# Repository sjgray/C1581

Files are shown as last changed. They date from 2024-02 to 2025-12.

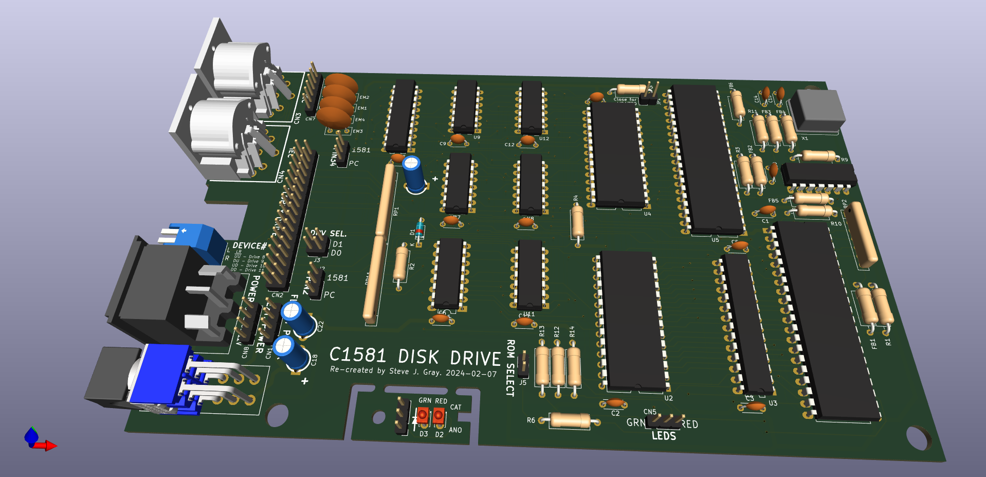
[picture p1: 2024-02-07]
Enhanced/PROTO1/_Pics/2024-02-07-pcb-render.png

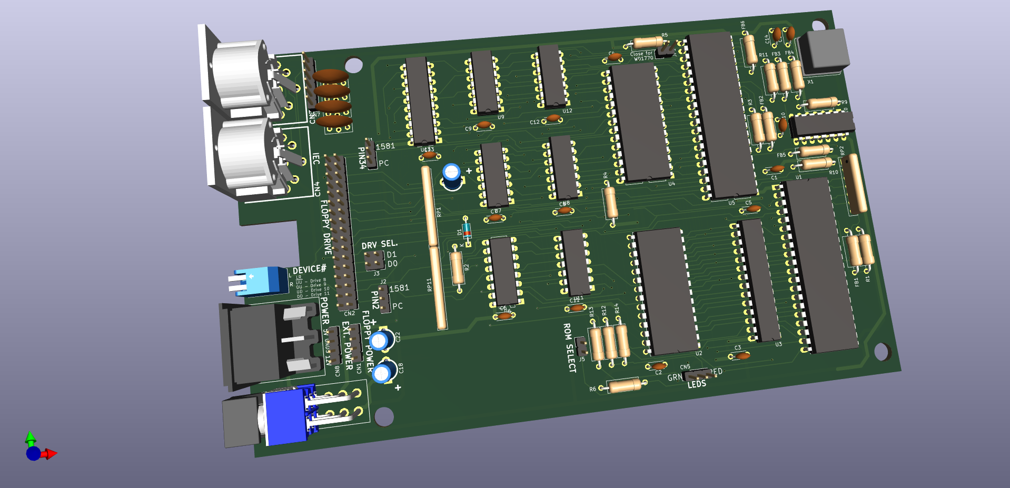
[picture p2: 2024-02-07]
Enhanced/PROTO1/_Pics/2024-02-06-pcb-render.png

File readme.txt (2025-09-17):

1581 ENHANCED PROJECT - Steve J. Gray
=====================

These are reproductions of the C1581 Disk Drive PCB.
The goal of this is to create enhanced PCBs which
can be modified, ie: reduced area for mounting 
inside a computer, increased ROM capacity, power
options, or laptop drive support, etc.

Enhancements:
- Jumpers for 1581/Amiga or PC drive.
- Jumpers for drive select 0 or 1.
- SkinnyDIP RAM chip.
- Double-size ROM with select (Standard or JiffyDOW).
- Optional header for 12V+5V internal power.
- Optional Barrel Jack for 12V power.
- Long pads for easier soldering.

ENHANCED
--------

This is a version with the same layout as the original,
with all original features and ports, plus all
enhancements. It can be installed in an original or
reproduction case. It includes the breakaway LED board.
It can also be powered with a 12V supply by replacing
the original 4-PIN DIN with the barrel jack.

INTERNAL
--------

This is a compact version with a slightly arranged
layout to pack the chips closer together. It removes
the DIN connectors, and LED breakaway.

*****************************************************
** The schematics and PCBs have NOT been verified! **
** Use at own risk!                                **
*****************************************************

Steve

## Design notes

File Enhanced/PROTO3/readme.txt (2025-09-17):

1581 ENHANCED VERSION - PROTO 2
===============================

This is a reproduction of the C1541 Disk Drive PCB.
The goal of this is to create an enhanced PCB which
can be modified, ie: reduced area for mounting 
inside a computer.

Enhancements:
- Jumpers for 1581/Amiga or PC drive.
- Jumpers for drive select 0 or 1.
- SkinnyDIP RAM chip.
- Double-size ROM with select (Standard or JiffyDOW).
- Optional header for 12V+5V internal power.
- Optional Barrel Jack for 12V power.
- Long pads for easier soldering.

*********************************************
*** DESIGN NOT VERIFIED! USE AT OWN RISK! ***
*********************************************

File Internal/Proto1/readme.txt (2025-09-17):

1581i - Internal Version - PROTO 1
========================

This is a reproduction of the C1581 Disk Drive PCB.
The goal of this is to create an enhanced PCB which
can be modified, ie: reduced area for mounting 
inside a computer.

Enhancements:
- Jumpers for 1581/Amiga or PC drive.
- Jumpers for drive select 0 or 1.
- SkinnyDIP RAM chip.
- Double-size ROM with select (Standard or JiffyDOW).
- Optional header for 12V+5V internal power.
- Optional Barrel Jack for 12V power.
- FPC connector for Laptop PC Drive.
- Long pads for easier soldering.

**** THIS VERSION HAS ERRORS! **** Use PROTO 2!
Steve

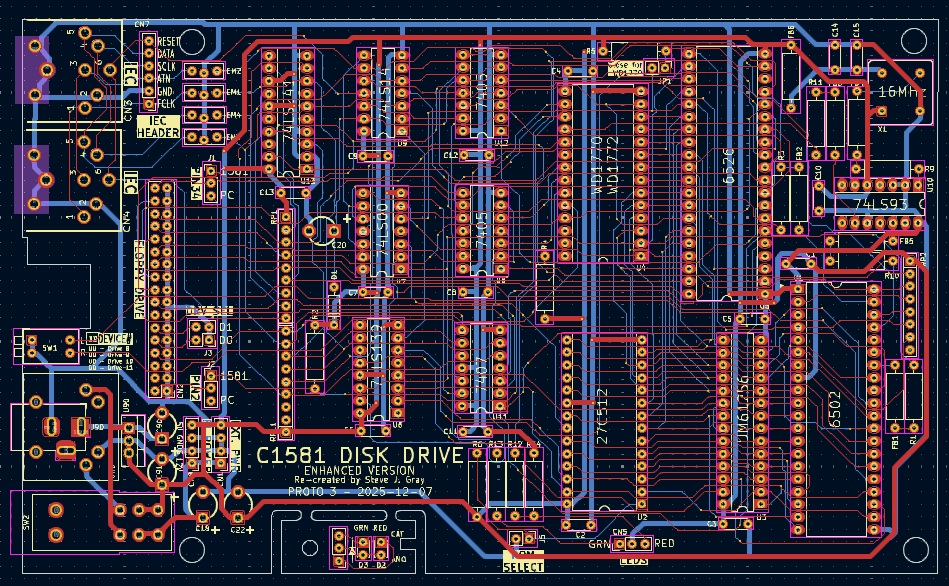
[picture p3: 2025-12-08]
Enhanced/PROTO3/_Pics/routed.jpg

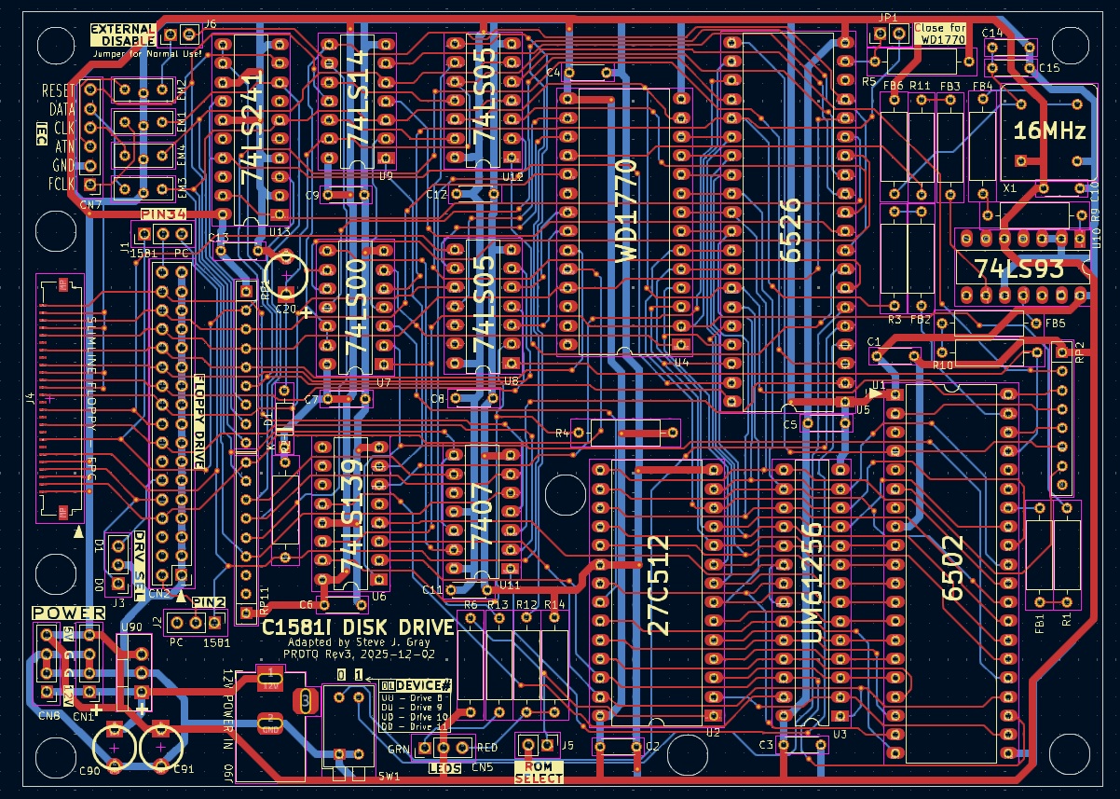
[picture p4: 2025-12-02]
Internal/Proto3/_Pics/2025-12-02-Routed.jpg

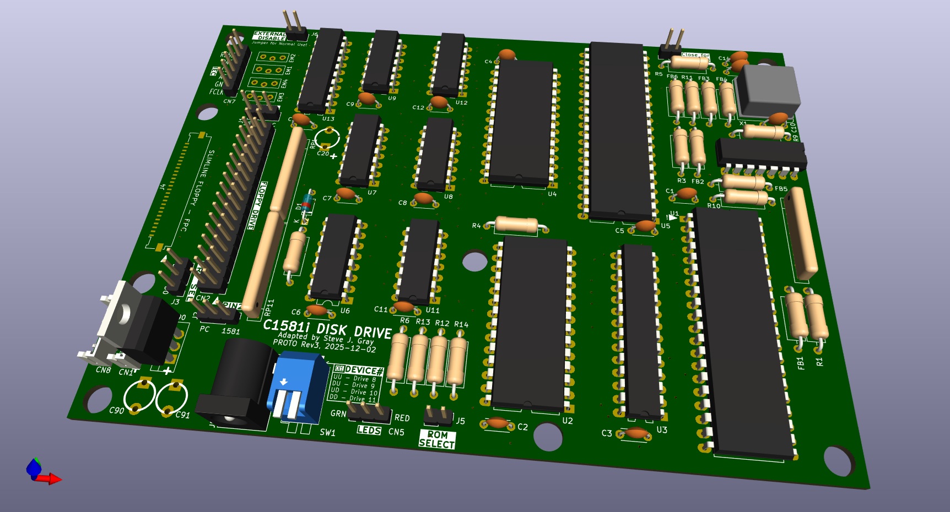
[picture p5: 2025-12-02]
Internal/Proto3/_Pics/2025-12-02-Render-angle.jpg

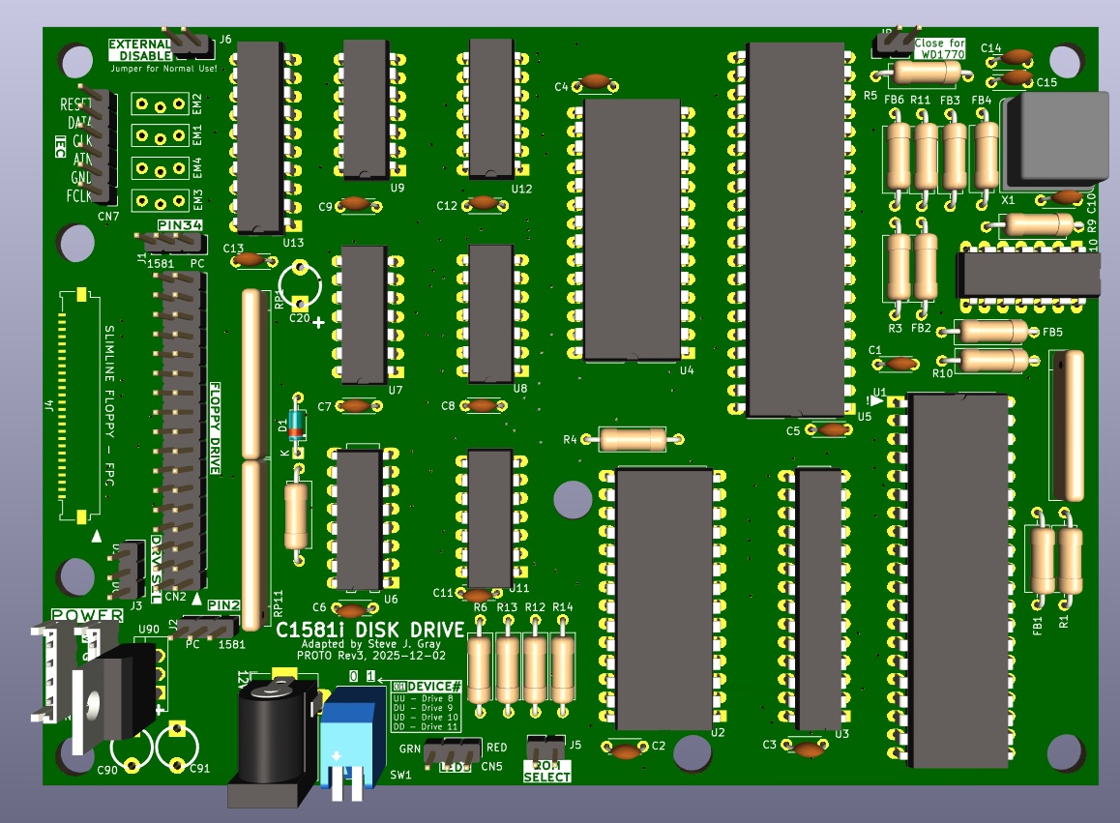
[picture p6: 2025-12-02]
Internal/Proto3/_Pics/2025-12-02-Render-top.jpg

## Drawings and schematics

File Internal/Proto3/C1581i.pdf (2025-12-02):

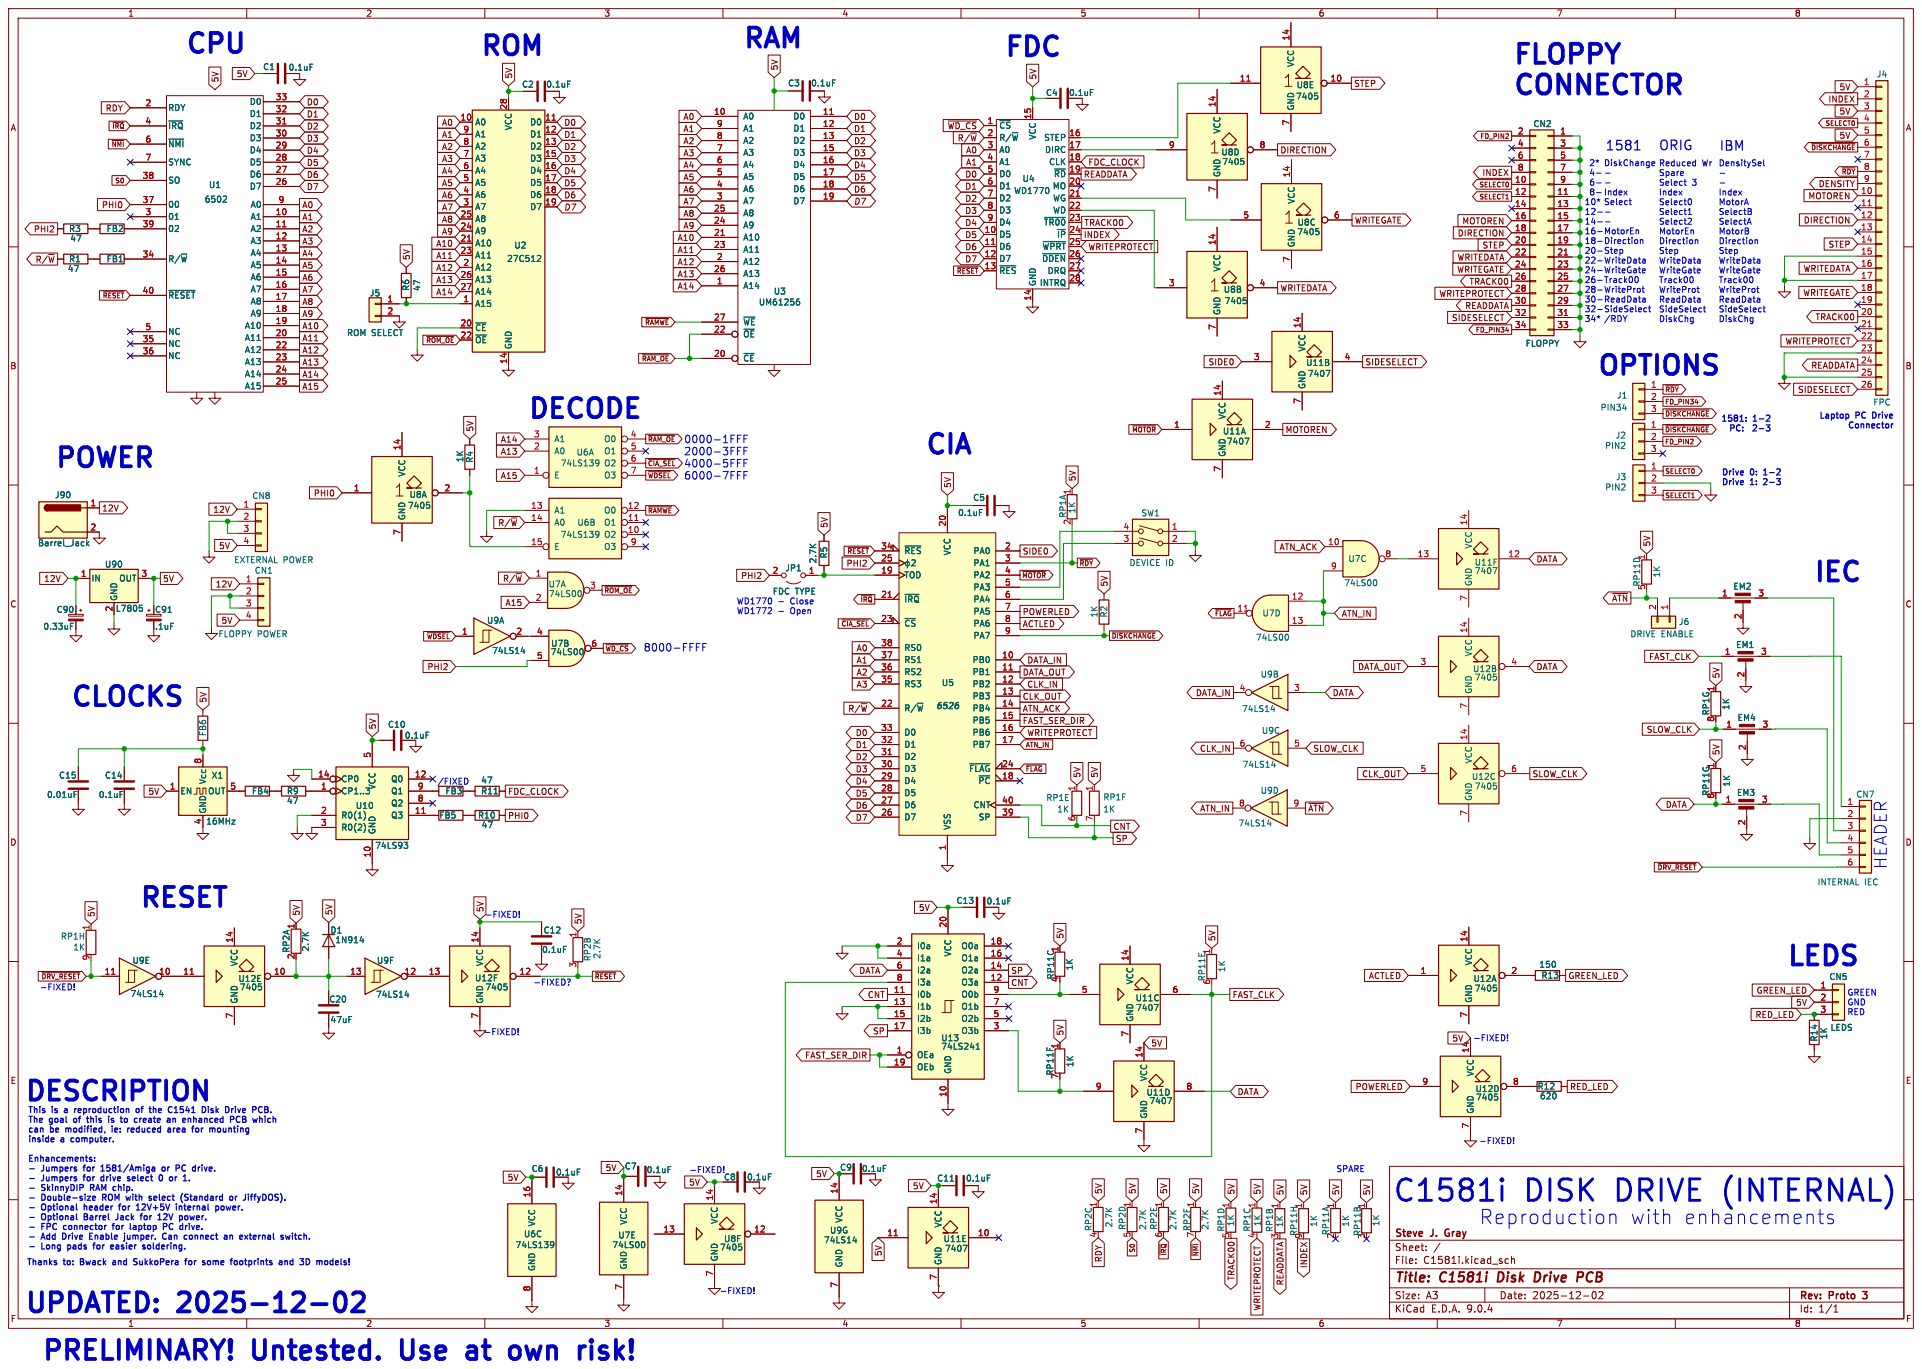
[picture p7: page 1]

INDEX
Drive 0: 1-2 Drive 1: 2-3 Reduced Wr Spare Select 3

1581 ORIG
Index Select0 Select1 Select2 MotorEn Direction Step WriteData WriteGate Track00 WriteProt ReadData SideSelect DiskChg
-MotorEn Direction Step WriteData WriteGate Track00 WriteProt ReadData SideSelect
SelectA MotorB Direction Step WriteData WriteGate Track00 WriteProt ReadData SideSelect DiskChg

/RDY
Laptop PC Drive Connector IEC

1 PA0 2 PA1 3 PA2 4 PA3 5 PA4 6 PA5 7 PA6 8 PA7 9 PB0 10 PB1 11 PB2 12 PB3 13 PB4 14 PB5 15 PB6 16 PB7 17 ~{FLAG}24 ~{PC} 18 CNT 40 SP 39 U5

1 PA0 2 PA1 3 PA2 4 PA3 5 PA4 6 PA5 7 PA6 8 PA7 9 PB0 10 PB1 11 PB2 12 PB3 13 PB4 14 PB5 15 PB6 16 PB7 17 ~{FLAG}24 ~{PC} 18 CNT 40 SP 39 EM4

can be modified, ie: reduced area for mounting
inside a computer. Enhancements:

File: C1581i.kicad_sch Sheet: / Steve J. Gray

Thanks to: Bwack and SukkoPera for some footprints and 3D models! PRELIMINARY! Untested. Use at own risk!

Id: 1/1 Title: C1581i Disk Drive PCB

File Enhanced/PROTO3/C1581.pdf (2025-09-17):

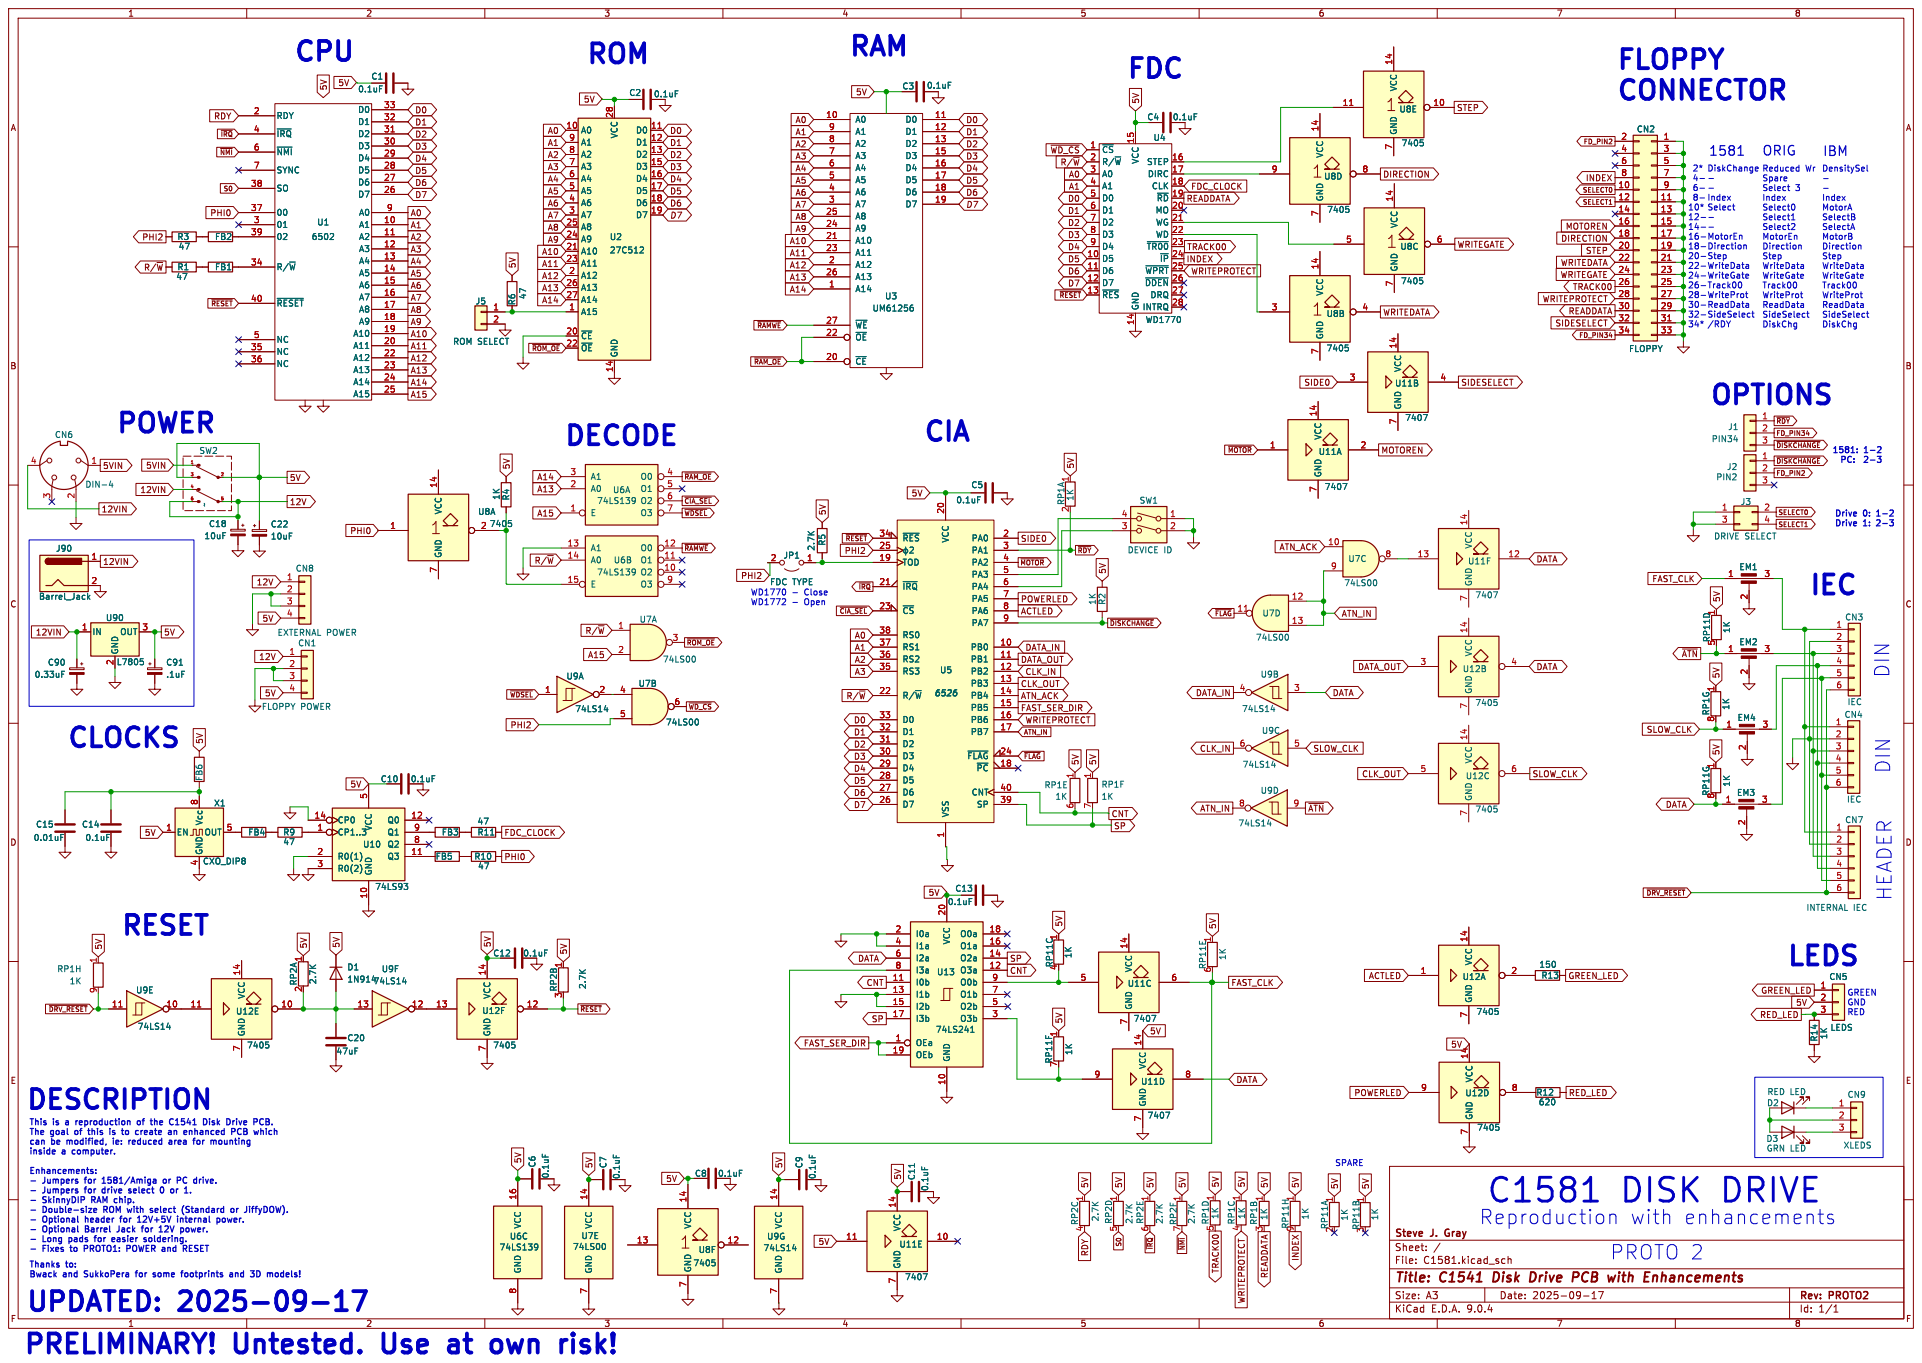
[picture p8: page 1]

Index Select0 Select1 Select2 MotorEn Direction Step WriteData WriteGate Track00 WriteProt ReadData SideSelect DiskChg

Reduced Wr Spare Select 3

TRACK00 WRITEGATE WRITEDATA DIRECTION MOTOREN WRITEDATA MOTOREN

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

1 PA0 2 PA1 3 PA2 4 PA3 5 PA4 6 PA5 7 PA6 8 PA7 9 PB0 10 PB1 11 PB2 12 PB3 13 PB4 14 PB5 15 PB6 16 PB7 17 ~{FLAG}24 ~{PC} 18 CNT 40 SP 39 R14 1K CN5

INTERNAL IEC VCC 14 GND
7407 VCC 14 GND
FAST_CLK DATA

Thanks to: Bwack and SukkoPera for some footprints and 3D models! DESCRIPTION

can be modified, ie: reduced area for mounting
inside a computer. Enhancements:

File: C1581.kicad_sch Sheet: / Steve J. Gray VCC 14 GND

Id: 1/1 Title: C1541 Disk Drive PCB with Enhancements

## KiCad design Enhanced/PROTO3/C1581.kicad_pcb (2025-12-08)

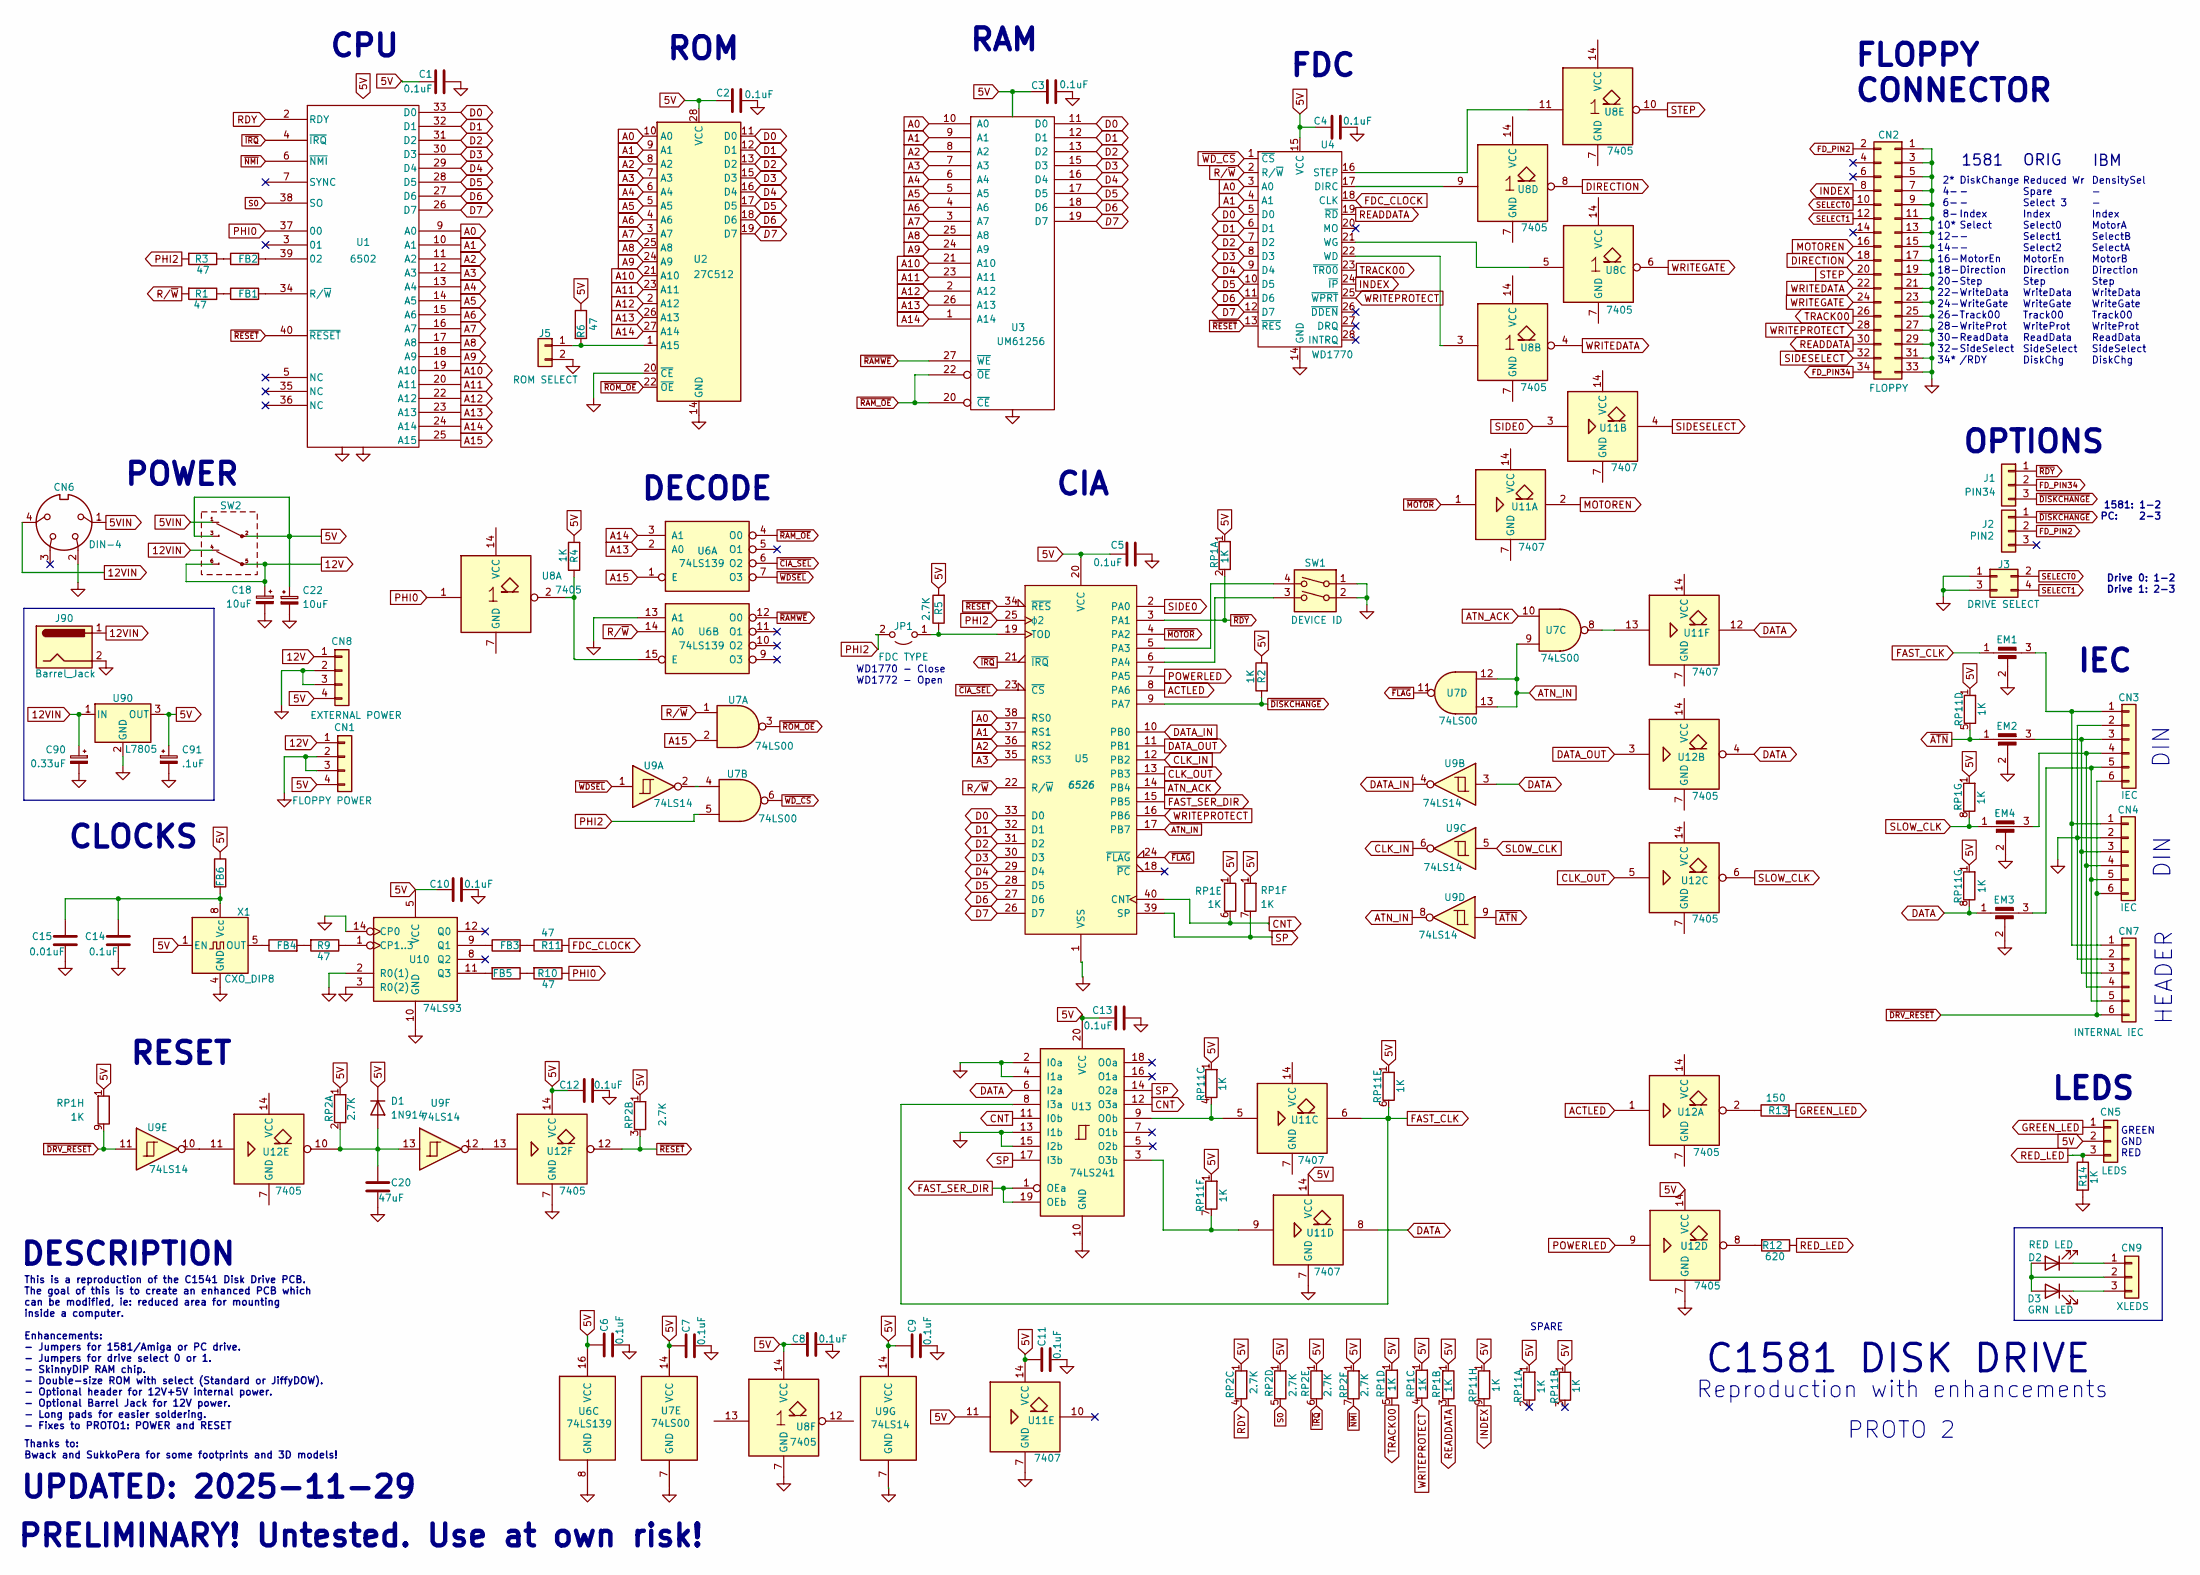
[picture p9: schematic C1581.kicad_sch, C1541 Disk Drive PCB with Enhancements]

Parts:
C1, C2, C3, C4, C5, C6, C7, C8, C9, C10, C11, C12, C13, C14: 0.1uF; C_Disc_D4.3mm_W1.9mm_P5.00mm
C15: 0.01uF; C_Disc_D4.3mm_W1.9mm_P5.00mm
C18, C22: 10uF; CAP_RADIAL_P5.08MM_D6MM
C20: 47uF; CAP_RADIAL_P5.08MM_D6MM
C90: 0.33uF; CAP_RADIAL_P5.08MM_D6MM
C91: .1uF; CAP_RADIAL_P5.08MM_D6MM
CN1: FLOPPY POWER; PinHeader_1x04_P2.54mm_Vertical
CN2: FLOPPY; PinHeader_2x17_P2.54mm_Vertical
CN3, CN4: IEC; SERIAL_CON_DIN6
CN5: LEDS; PinHeader_1x03_P2.54mm_Vertical
CN6: DIN-4
CN7: INTERNAL IEC; PinHeader_1x06_P2.54mm_Vertical
CN8: EXTERNAL POWER; PinHeader_1x04_P2.54mm_Vertical
CN9: XLEDS; PinHeader_1x03_P2.54mm_Vertical
D1: 1N914; D_DO-35_SOD27_P7.62mm_Horizontal
D2: RED LED; LED_D1.8mm_W3.3mm_H2.4mm
D3: GRN LED; LED_D1.8mm_W3.3mm_H2.4mm
EM1, EM2, EM3, EM4: 100pf; EMI_Filter
FB1, FB2, FB3, FB4, FB5, FB6: FB; R_Axial_DIN0309_L9.0mm_D3.2mm_P12.70mm_Horizontal
J1: PIN34; PinHeader_1x03_P2.54mm_Vertical
J2: PIN2; PinHeader_1x03_P2.54mm_Vertical
J3: DRIVE SELECT; PinHeader_2x02_P2.54mm_Vertical
J5: ROM SELECT; PinHeader_1x02_P2.54mm_Vertical
J90: Barrel_Jack; BarrelJack_Horizontal
JP1: FDC TYPE; PinHeader_1x02_P2.54mm_Vertical
R1, R3, R6, R9, R10, R11: 47; R_Axial_DIN0309_L9.0mm_D3.2mm_P12.70mm_Horizontal
R2, R4, R14: 1K; R_Axial_DIN0309_L9.0mm_D3.2mm_P12.70mm_Horizontal
R5: 2.7K; R_Axial_DIN0309_L9.0mm_D3.2mm_P12.70mm_Horizontal
R12: 620; R_Axial_DIN0309_L9.0mm_D3.2mm_P12.70mm_Horizontal
R13: 150; R_Axial_DIN0309_L9.0mm_D3.2mm_P12.70mm_Horizontal
RP1, RP11: 1K; R_Array_SIP9
RP2: 2.7K; R_Array_SIP8
SW1: DEVICE ID; SW_DIP_SPSTx02_Piano_10.8x6.64mm_W7.62mm_P2.54mm
SW2: C64_PowerSwitch
U1: 6502; DIP-40_W15.24mm_LongPads
U2: 27C512; DIP-28_W15.24mm
U3: UM61256; DIP-28_W7.62mm_LongPads
U4: WD1770; DIP-28_W15.24mm_LongPads
U5: 6526; DIP-40_W15.24mm_LongPads
U6: 74LS139; DIP-16_W7.62mm_LongPads
U7: 74LS00; DIP-14_W7.62mm_LongPads
U8, U12: 7405; DIP-14_W7.62mm_LongPads
U9: 74LS14; DIP-14_W7.62mm_LongPads
U10: 74LS93; DIP-14_W7.62mm_LongPads
U11: 7407; DIP-14_W7.62mm_LongPads
U13: 74LS241; DIP-20_W7.62mm_LongPads
U90: L7805; TO-220-3_Vertical
X1: CXO_DIP8; Oscillator_DIP-8

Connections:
5V: C1.1, C2.1, C3.1, C4.1, C5.1, C6.1, C7.1, C8.1, C9.1, C10.1, C11.1, C12.1, C13.1, C22.1, C91.1, CN1.4, CN5.2, CN8.4, D1.1 (K), FB6.1, R2.1, R4.2, R5.2, R6.1, RP1.1 (R1), RP2.1 (R1), RP11.1 (R1), SW2.2, SW2.3, U1.8 (Vcc), U2.28 (VCC), U3.28 (VCC), U4.15 (VCC), U5.20 (VCC), U6.16 (VCC), U7.14 (VCC), U8.14 (VCC), U9.14 (VCC), U10.5 (VCC), U11.11, U11.14 (VCC), U12.14 (VCC), U13.20 (VCC), U90.3 (OUT), X1.1 (EN)
5VIN: CN6.1, SW2.1
12V: C18.1, CN1.1, CN8.1, SW2.5, SW2.6
12VIN: C90.1, CN6.4, J90.1, SW2.4, U90.1 (IN)
A0: U1.9 (A0), U2.10 (A0), U3.10 (A0), U4.3 (A0), U5.38 (RS0)
A1: U1.10 (A1), U2.9 (A1), U3.9 (A1), U4.4 (A1), U5.37 (RS1)
A2: U1.11 (A2), U2.8 (A2), U3.8 (A2), U5.36 (RS2)
A3: U1.12 (A3), U2.7 (A3), U3.7 (A3), U5.35 (RS3)
A4: U1.13 (A4), U2.6 (A4), U3.6 (A4)
A5: U1.14 (A5), U2.5 (A5), U3.5 (A5)
A6: U1.15 (A6), U2.4 (A6), U3.4 (A6)
A7: U1.16 (A7), U2.3 (A7), U3.3 (A7)
A8: U1.17 (A8), U2.25 (A8), U3.25 (A8)
A9: U1.18 (A9), U2.24 (A9), U3.24 (A9)
A10: U1.19 (A10), U2.21 (A10), U3.21 (A10)
A11: U1.20 (A11), U2.23 (A11), U3.23 (A11)
A12: U1.22 (A12), U2.2 (A12), U3.2 (A12)
A13: U1.23 (A13), U2.26 (A13), U3.26 (A13), U6.2 (A0)
A14: U1.24 (A14), U2.27 (A14), U3.1 (A14), U6.3 (A1)
A15: U1.25 (A15), U6.1 (E), U7.2
ACTLED: U5.8 (PA6), U12.1
ATN_ACK: U5.14 (PB4), U7.10
ATN_IN: U5.17 (PB7), U7.9, U7.12, U7.13, U9.8
CLK_IN: U5.12 (PB2), U9.6
CLK_OUT: U5.13 (PB3), U12.5
CNT: RP1.6 (R5.2), U5.40 (CNT), U13.11 (I0b), U13.12 (O3a)
D0: U1.33 (D0), U2.11 (D0), U3.11 (D0), U4.5 (D0), U5.33 (D0)
D1: U1.32 (D1), U2.12 (D1), U3.12 (D1), U4.6 (D1), U5.32 (D1)
D2: U1.31 (D2), U2.13 (D2), U3.13 (D2), U4.7 (D2), U5.31 (D2)
D3: U1.30 (D3), U2.15 (D3), U3.15 (D3), U4.8 (D3), U5.30 (D3)
D4: U1.29 (D4), U2.16 (D4), U3.16 (D4), U4.9 (D4), U5.29 (D4)
D5: U1.28 (D5), U2.17 (D5), U3.17 (D5), U4.10 (D5), U5.28 (D5)
D6: U1.27 (D6), U2.18 (D6), U3.18 (D6), U4.11 (D6), U5.27 (D6)
D7: U1.26 (D7), U2.19 (D7), U3.19 (D7), U4.12 (D7), U5.26 (D7)
DATA: EM3.1, RP11.8 (R7.2), U9.3, U11.8, U11.12, U12.4, U13.6 (I2a)
DATA_IN: U5.10 (PB0), U9.4
DATA_OUT: U5.11 (PB1), U12.3
DIRECTION: CN2.18, U8.8
FAST_CLK: EM1.1, RP11.6 (R5.2), U11.6, U13.8 (I3a)
FAST_SER_DIR: U5.15 (PB5), U13.1 (OEa), U13.19 (OEb)
FDC_CLOCK: R11.2, U4.18 (CLK)
FD_PIN2: CN2.2, J2.2
FD_PIN34: CN2.34, J1.2
GND: C1.2, C2.2, C3.2, C4.2, C5.2, C6.2, C7.2, C8.2, C9.2, C10.2, C11.2, C12.2, C13.2, C14.2, C15.2, C18.2, C20.2, C22.2, C90.2, C91.2, CN1.2, CN1.3, CN2.1, CN2.3, CN2.5, CN2.7, CN2.9, CN2.11, CN2.13, CN2.15, CN2.17, CN2.19, CN2.21, CN2.23, CN2.25, CN2.27, CN2.29, CN2.31, CN2.33, CN3.2, CN4.2, CN6.2, CN7.2, CN8.2, CN8.3, EM1.2, EM2.2, EM3.2, EM4.2, J3.1, J3.3, J5.2, J90.2, R14.2, SW1.1, SW1.2, U1.1 (VSS), U1.21 (GND), U2.14 (GND), U2.20 (~CE), U3.14 (GND), U4.14 (GND), U5.1 (VSS), U6.8 (GND), U6.13 (A1), U7.7 (GND), U8.7 (GND), U9.7 (GND), U10.2 (R0(1)), U10.3 (R0(2)), U10.10 (GND), U10.14 (CP0), U11.7 (GND), U12.7 (GND), U13.2 (I0a), U13.4 (I1a), U13.10 (GND), U13.13 (I1b), U13.15 (I2b), U90.2 (GND), X1.4 (GND)
GREEN_LED: CN5.1, R13.2
INDEX: CN2.8, RP11.9 (R8.2), U4.24 (~IP)
MOTOREN: CN2.16, U11.2
unnamed: CN3.1, CN4.1, CN7.1, EM1.3
unnamed: CN3.3, CN4.3, CN7.3, EM2.3
unnamed: CN3.4, CN4.4, CN7.4, EM4.3
unnamed: CN3.5, CN4.5, CN7.5, EM3.3
unnamed: CN9.1, D2.1 (K)
unnamed: CN9.2, D2.2 (A), D3.2 (A)
unnamed: CN9.3, D3.1 (K)
unnamed: C20.1, D1.2 (A), RP2.2 (R1.2), U9.13, U12.10
unnamed: FB1.1, R1.1
unnamed: FB2.1, R3.1
unnamed: FB3.2, R11.1
unnamed: FB4.2, R9.2
unnamed: FB5.1, R10.2
unnamed: J5.1, R6.2, U2.1 (A15)
unnamed: JP1.1 (A), R5.1, U5.19 (TOD)
unnamed: R12.2, U12.8
unnamed: R13.1, U12.2
unnamed: RP11.4 (R3.2), U11.5, U13.9 (O0b)
unnamed: RP11.7 (R6.2), U11.9, U13.3 (O3b)
unnamed: FB2.2, U1.39 (02)
unnamed: FB1.2, U1.34 (R/~W)
unnamed: U4.17 (DIRC), U8.9
unnamed: U4.16 (STEP), U8.11
unnamed: U4.22 (WD), U8.3
unnamed: U4.21 (WG), U8.5
unnamed: SW1.4, U5.5 (PA3)
unnamed: SW1.3, U5.6 (PA4)
unnamed: R4.1, U6.15 (E), U8.2
unnamed: U7.4, U9.2
unnamed: R9.1, U10.1 (CP1..3)
unnamed: FB3.1, U10.9 (Q1)
unnamed: FB5.2, U10.11 (Q3)
unnamed: U7.8, U11.13
unnamed: U9.10, U12.11
unnamed: U9.12, U12.13
unnamed: FB4.1, X1.5 (OUT)
unnamed: C14.1, C15.1, FB6.2, X1.8 (Vcc)
PHI0: R10.1, U1.37 (00), U8.1
PHI2: JP1.2 (B), R3.2, U5.25 (ϕ2), U7.5
POWERLED: U5.7 (PA5), U12.9
RDY: RP2.4 (R3.2), U1.2 (RDY)
READDATA: CN2.30, RP1.3 (R2.2), U4.19 (~RD)
RED_LED: CN5.3, R12.1, R14.1
R/~W: R1.2, U4.2 (R/~W), U5.22 (R/~W), U6.14 (A0), U7.1
S0: RP2.5 (R4.2), U1.38 (SO)
SELECT0: CN2.10, J3.2
SELECT1: CN2.12, J3.4
SIDE0: U5.2 (PA0), U11.3
SIDESELECT: CN2.32, U11.4
SLOW_CLK: EM4.1, RP1.8 (R7.2), U9.5, U12.6
SP: RP1.7 (R6.2), U5.39 (SP), U13.14 (O2a), U13.17 (I3b)
STEP: CN2.20, U8.10
TRACK00: CN2.26, RP1.5 (R4.2), U4.23 (~TR00)
WRITEDATA: CN2.22, U8.4
WRITEGATE: CN2.24, U8.6
WRITEPROTECT: CN2.28, RP1.4 (R3.2), U4.25 (~WPRT), U5.16 (PB6)
~ATN: EM2.1, RP11.5 (R4.2), U9.9
~CIA_SEL: U5.23 (~CS), U6.6 (O2)
~DISKCHANGE: J1.3, J2.1, R2.2, U5.9 (PA7)
~DRV_RESET: CN3.6, CN4.6, CN7.6, RP1.9 (R8.2), U9.11
~FLAG: U5.24 (~FLAG), U7.11
~IRQ: RP2.6 (R5.2), U1.4 (~IRQ), U5.21 (~IRQ)
~MOTOR: U5.4 (PA2), U11.1
~NMI: RP2.7 (R6.2), U1.6 (~NMI)
~RAMWE: U3.27 (~WE), U6.12 (O0)
~RAM_OE: U3.20 (~CE), U3.22 (~OE), U6.4 (O0)
~RDY: J1.1, RP1.2 (R1.2), U5.3 (PA1)
~RESET: RP2.3 (R2.2), U1.40 (~RESET), U4.13 (~RES), U5.34 (~RES), U12.12
~ROM_OE: U2.22 (~OE), U7.3
~WDSEL: U6.7 (O3), U9.1
~WD_CS: U4.1 (~CS), U7.6

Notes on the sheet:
DECODE
UPDATED: 2025-11-29
ORIG
Drive 0: 1-2 Drive 1: 2-3
Reduced Wr Spare Select 3 Index Select0 Select1 Select2 MotorEn Direction Step WriteData WriteGate Track00 WriteProt ReadData SideSelect DiskChg
2* 4- 6- 8- 10* 12- 14- 16- 18- 20- 22- 24- 26- 28- 30- 32- 34*
DiskChange - - Index Select - - MotorEn Direction Step WriteData WriteGate Track00 WriteProt ReadData SideSelect /RDY
CLOCKS
POWER
ROM
DIN
HEADER
CIA
LEDS
RESET
DensitySel - - Index MotorA SelectB SelectA MotorB Direction Step WriteData WriteGate Track00 WriteProt ReadData SideSelect DiskChg
RAM
This is a reproduction of the C1541 Disk Drive PCB. The goal of this is to create an enhanced PCB which can be modified, ie: reduced area for mounting inside a computer. Enhancements: - Jumpers for 1581/Amiga or PC drive. - Jumpers for drive select 0 or 1. - SkinnyDIP RAM chip. - Double-size ROM wi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
FLOPPY CONNECTOR
1581
IBM
C1581 DISK DRIVE
CPU
PRELIMINARY! Untested. Use at own risk!
Thanks to: Bwack and SukkoPera for some footprints and 3D models!
1581: 1-2 PC: 2-3
DESCRIPTION
OPTIONS
GREEN GND RED
SPARE
FDC
Reproduction with enhancements
WD1770 - Close WD1772 - Open
IEC
PROTO 2

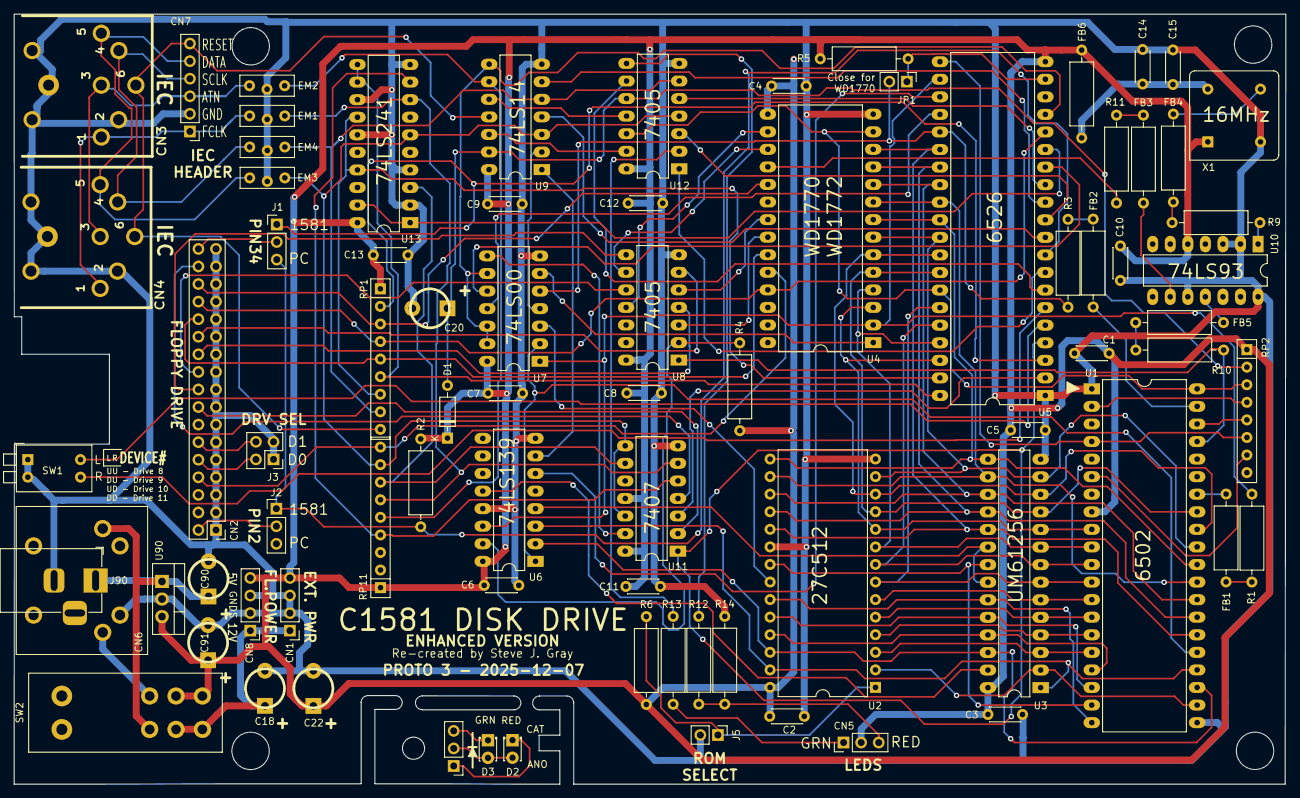
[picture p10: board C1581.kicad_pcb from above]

Board: 2 copper layers, 183.9 x 111.3 mm, 80 parts (0 on the bottom side), 118 nets.

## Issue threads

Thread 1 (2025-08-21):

PCB internal schematics errors.

defleppardt, 2025-08-21:
I procured a C1581 internal PCB and assembled the components. The C1581 didn't work. I checked the PCB against the C1581 schematics. I found several errors on the PCB. I corrected the errors and tested it, but it still didn't work. Your PCB schematics contain numerous errors.

defleppardt, 2025-08-22:
I found other issues and corrected them, and the PCB worked. The problems are: the RESET short goes directly to the output line. The line needs to be cut near U12 pin 12. The WD1770 CLK pin 18 doesn't go to pin 9 on the LS93. The line goes to pin 12. I cut it and soldered it to pin 9. WD1770 doesn't reset to pin 13. Some things might not need to be corrected according to the original schematic, but the RESET short is. GND +5V must be connected to the 7406s. I solved the problem and got it working after correcting the errors. Thanks.

sjgray, 2025-08-22:
I appreciate you taking the time to respond. That's amazing that you got it working! I believe the 7405 and 7406 are the same pinout. Kicad may not have had the correct one in the library. Did you make the corrections in kicad? Do you want to push an update or send the files and I will be sure to credit them to you. If not, no worries I will correct them when I get a chance. I'm not sure when I will be able to get to building one myself though. So many projects...

Marco-Both, 2025-09-16:
Hi, I had PCBs made before I read this. 😩 I'm glad there's a solution. I'm happy to fix all the errors in KiCad and make a commit. @defleppardt  A list of the errors would be very helpful for this.
Thank you.

sjgray, 2025-09-16:
That's great thanks! Hopefully I can fix the issues this evening.

Marco-Both, 2025-09-17:
Oh cool. Have you already implemented the corrections?

sjgray, 2025-09-17:
> Oh cool. Have you already implemented the corrections?

Yes, I am busy most of the day, but will finalize things this evening and post.

sjgray, 2025-09-17:
PROTO 2 has been released.

Closed 2025-09-17.

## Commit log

2024-02-07 Initial Design
    This is a 1581 disk drive PCB with enhancements, created in Kicad.
    [C1581.kicad_sch]
2024-02-08 Update to readme
    Update readme and fix some typos.
    [C1581i.kicad_sch]
2024-02-08 Add 1581i Internal Version
    Smaller, for mounting inside a computer case. Removes DIN headers, and packs components closer together.
    [C1581i.kicad_pcb, C1581i.kicad_sch]
2024-02-09 1581i Update
    Lots of re-routing to pack components tighter. PCB is now smaller. Added FPC connector to add Laptop PC drive support. Add board render.
    [C1581i.kicad_pcb, C1581i.kicad_sch]
2024-02-09 Floppy connector area updates
    Move floppy connector and jumpers. Add additional mounting holes.
    [C1581i.kicad_pcb]
2024-02-12 Add Enable/Disable Jumper
    Allows use of an external switch to enable/disable the drive.
    [C1581i.kicad_pcb, C1581i.kicad_sch]
2024-02-15 1581i - Fix 12v power
    Fix 12V from barrel jack not connecting to floppy power. I am making a small run of boards from JLCPCB to test the design.
    [C1581i.kicad_pcb, C1581i.kicad_sch]
2024-02-15 1581i - fix typo, update pdf and render
    Fix typo in description. Update schematic PDF and board render.
    [C1581i.kicad_sch]
2024-05-07 Enhanced and Internal BOM
    Add interactive BOM
2025-09-17 Release PROTO 2
    Fixed reported errors with power missing from a couple chips, plus reset. Added improved labelling and trace optimization. Not tested by me. Use at own risk.
    [C1581i-B_Cu.gbr, C1581i-B_Mask.gbr, C1581i-B_Paste.gbr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]
2025-09-17 Uppdate to PROTO2 files
    Updated PDF and board JPG
2025-09-17 Release Enhanced PROTO2
    With fixes to power and reset, and updated labelling.
    [C1581-B_Cu.gbr, C1581-B_Mask.gbr, C1581-B_Paste.gbr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]
2025-09-17 Update readme
    These designs are untested. Use at own risk. Gerbers are provided for those that would like to help or provide feedback to the project.
2025-11-30 Add EMI component values
    Add missing EMI component values and generated new Interactive BOMs for both Enhanced and Internal Proto2 designs.
    [C1581.kicad_pcb, C1581.kicad_sch, C1581i.kicad_pcb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]
2025-12-02 Add Internal Proto3
    Fixed trace to FPC, moved floppy connector to make more space for FPC cable
    [C1581i-B_Cu.gbr, C1581i-B_Mask.gbr, C1581i-B_Paste.gbr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]
2025-12-08 Enhanced Proto#3
    Fix missing R5 trace. Update labels. Generate new gerbers.
    [C1581-B_Cu.gbr, C1581-B_Mask.gbr, C1581-B_Paste.gbr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]
